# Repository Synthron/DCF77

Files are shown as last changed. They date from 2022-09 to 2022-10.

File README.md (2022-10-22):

# DCF77

DCF77-Clock with Multi-LED display with STM32

---

## Decription

This DCF77 Clock not only displays the time and date, but also analyzes and visualizes the signal received.  
The LED rings are placed as such that each LED is on its respective position on a standard clock face.  
The 7 Segment Displays show the time and date in a more readable format.

### Inner LED Ring

The inner LED ring clocks in the data for the current minute telegram. Each "1"-bit will be displayed by the LED lit up, on a "0", the LED is off respectively.

### Outer LED Ring

The outer LED ring gets updated after the current minute data is complete. On the "0-Second"-Mark, the data from the inner ring gets pushed to the outer ring and analyzed. The resulting data will then be displayed on the 7-Segment-Displays as well as the status LEDs. Also at each full hour, the internal RTC gets updated.

### RTC behaviour

1. Initial startup  
After the initial power-up the current RTC value will be pushed to the displays. This time information can only be trusted, once the module has received a valid telegram and was not powered down for more than 3 days.  
2. First received data  
Once the first valid data was received, it will be pushed into the RTC to update it. After successful write, the RTC_LOCK-LED will be on to indicate trustful data stored in the RTC.  
3. On the hour  
To mitigate possible clock drift, the RTC will be updated on the full hour. This ensures up-to-date data stored in it.

---

## Roadmap Hardware

- [x] finalize schematic
- [x] Set footprints
- [x] decide LED layout
  - all on one board
  - ~~seperate frontpanel pcb~~
- [x] Draw Layout
- [x] Review by theBrutzler
- [x] Order Parts
- [x] check footprints
- [x] Order PCB
- [x] Assemble

---

## Roadmap Software

- [ ] get USB running (for Debug)
- [x] Get DCF77 Antenna working and bits decoded
- [x] get MCP7221 running
- [x] get shift registers running
- [x] set up flags for stats and data
- [x] get LED rings running
- [x] get RTC running
- [x] Sync everything to start of minute/second
- [ ] get everything running together

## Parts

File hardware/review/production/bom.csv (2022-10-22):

Designator | Footprint | Quantity | Value | LCSC Part #
AFF401, AFF402, AFF403, AFF404, AFF405, AFF406, AFF407, AFF408, AFF409, AFF410, AFF411, AFF412, AFF413, AFF414, AFF415, AFF416, AFF417, AFF418, AFF419, AFF420 | 7_Segment_SMD | 20 | LTS-6980HR
C1 | C_0805_2012Metric | 1 | 4µ7
C201, C301, C401, C402, C403, C404, C502, C505, C506, C508, C514, C515, C518, C521, C522, C523, C524, C525, C526 | C_0805_2012Metric | 19 | 100n
C501 | CP_Elec_10x10.5 | 1 | 0.22F/5V5
C503 | CP_Elec_5x5.8 | 1 | 100µ
C504, C507, C513, C516 | C_0805_2012Metric | 4 | 1µ
C509, C510, C511, C512 | C_0805_2012Metric | 4 | 20p
C517 | CP_Elec_5x5.8 | 1 | 10µ
C519, C520 | C_0805_2012Metric | 2 | 47p
D201, D202, D203, D204, D205, D206, D207, D208, D209, D210, D211, D212, D213, D214, D215, D216, D217, D218, D219, D220, D221, D222, D223, D224, D225, D226, D227, D228, D229, D230, D231, D232, D233, D234, D235, D236, D237, D238, D239, D240, D241, D242, D243, D244, D245, D246, D247, D248, D249, D250, D251, D252, D253, D254, D255, D256, D257, D258, D259, D301, D302, D303, D304, D305, D306, D307, D308, D309, D310, D311, D312, D313, D314, D315, D316, D317, D318, D319, D320, D321, D322, D323, D324, D325, D326, D327, D328, D329, D330, D331, D332, D333, D334, D335, D336, D337, D338, D339, D340, D341, D342, D343, D344, D345, D346, D347, D348, D349, D350, D351, D352, D353, D354, D355, D356, D357, D358, D359 | LED_0603_1608Metric | 118 | LED
D401 | LED_0603_1608Metric | 1 | Mo
D402 | LED_0603_1608Metric | 1 | Di
D403 | LED_0603_1608Metric | 1 | Mi
D404 | LED_0603_1608Metric | 1 | Do
D405 | LED_0603_1608Metric | 1 | Fr
D406 | LED_0603_1608Metric | 1 | Sa
D407 | LED_0603_1608Metric | 1 | So
D408 | LED_0603_1608Metric | 1 | CET
D409 | LED_0603_1608Metric | 1 | CEST
D410 | LED_0603_1608Metric | 1 | P1
D411 | LED_0603_1608Metric | 1 | P2
D412 | LED_0603_1608Metric | 1 | P3
D413 | LED_0603_1608Metric | 1 | PE
D501 | D_MiniMELF | 1 | LL4148
D502 | D_MELF | 1 | SM4007
D503 | LED_0603_1608Metric | 1 | RTC
D504 | LED_0603_1608Metric | 1 | SIG
D505, D506 | SOT-23 | 2 | BAV199
FB501, FB502 | SMB-001 | 2 | FerriteBead
J501 | BarrelJack_Horizontal | 1 | Jack-DC
J502 | PinHeader_1x04_P2.54mm_Vertical | 1 | DCF77 Antenna
J503 | PinHeader_1x04_P2.54mm_Horizontal | 1 | SWD
J504 | USB_B_OST_USB-B1HSxx_Horizontal | 1 | USB_B
Q401, Q402, Q403, Q404, Q405, Q406, Q407, Q408, Q409, Q410, Q411, Q412, Q413, Q501, Q502, Q503, Q504, Q505, Q506, Q507, Q509, Q510, Q511 | SOT-23 | 23 | BSS138
Q508 | SOT-23 | 1 | BC856
R201, R301, R427, R428, R442 | R_0805_2012Metric | 5 | 20k
R401, R402, R403, R404, R405, R406, R407, R408, R409, R410, R411, R412, R413 | R_0805_2012Metric | 13 | R
R414, R416, R418, R420, R422, R424, R426, R430, R432, R434, R436, R438, R440, R501, R502, R503, R506, R508, R511, R512, R513, R514, R516, R518, R519, R520, R521, R523, R528, R529, R535, R536 | R_0805_2012Metric | 32 | 10k
R415, R417, R419, R421, R423, R425, R429, R431, R433, R435, R437, R439, R441, R504, R509, R515, R517, R522, R525, R527, R532, R533, R537 | R_0805_2012Metric | 23 | 100k
R505 | R_0805_2012Metric | 1 | 100
R507, R524, R526 | R_0805_2012Metric | 3 | 1k
R510 | R_0805_2012Metric | 1 | 1M
R530 | R_0805_2012Metric | 1 | 1k5
R531, R534 | R_0805_2012Metric | 2 | 22
U201, U301, U402, U403, U405 | SOIC-24W_7.5x15.4mm_P1.27mm | 5 | MAX7221xWG
U401, U404 | SO-16_3.9x9.9mm_P1.27mm | 2 | 74HC595
U501 | TO-263-2 | 1 | L7805
U502 | SOT-223-3_TabPin2 | 1 | AZ1117-3.3
U503 | LQFP-48_7x7mm_P0.5mm | 1 | STM32F103C8Tx
Y501 | Crystal_SMD_HC49-SD | 1 | 8MHz
Y502 | Crystal_SMD_SeikoEpson_MC306-4Pin_8.0x3.2mm | 1 | 32.768kHz

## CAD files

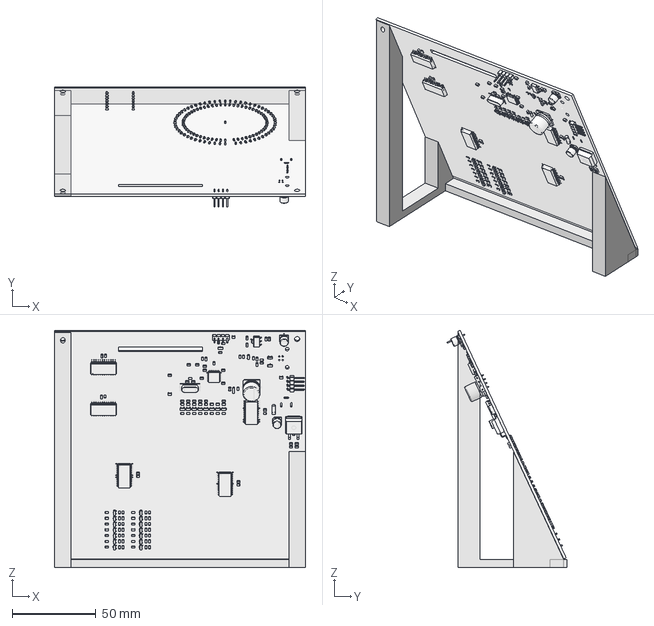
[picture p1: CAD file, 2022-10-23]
hardware/DCF77-Stand_Prototype.FCStd
150.0 x 71.6 x 141.8 mm
PCB

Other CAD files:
hardware/DCF77-Stand_Prototype.stl

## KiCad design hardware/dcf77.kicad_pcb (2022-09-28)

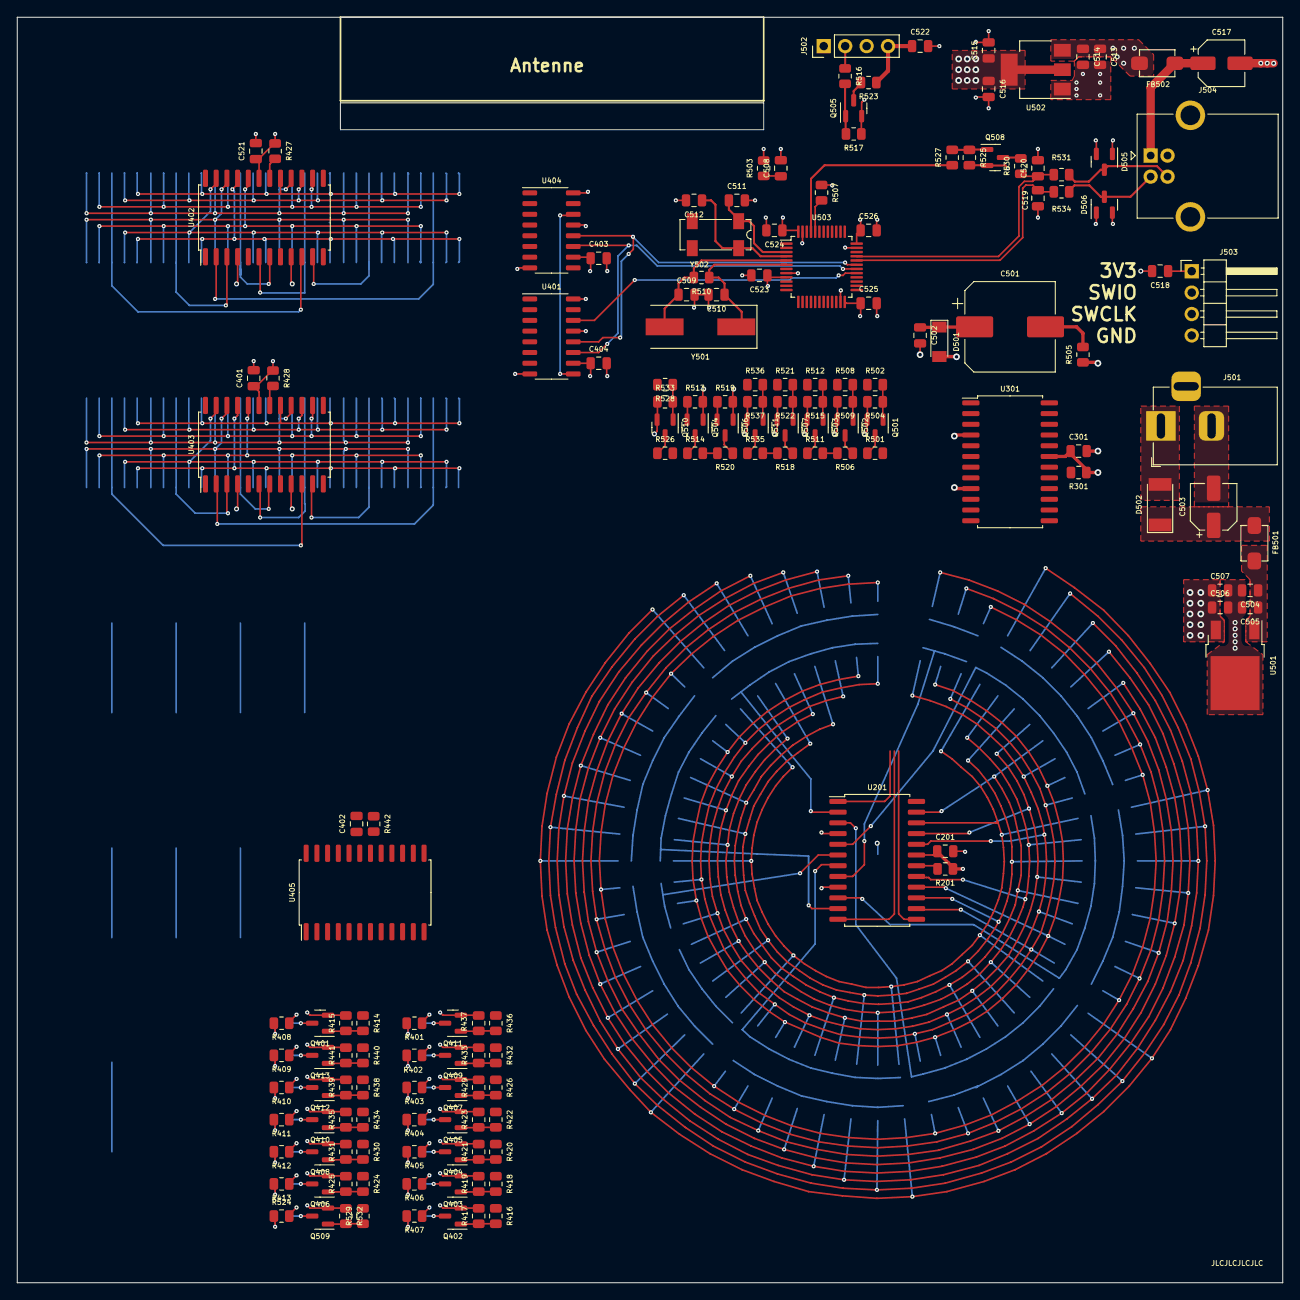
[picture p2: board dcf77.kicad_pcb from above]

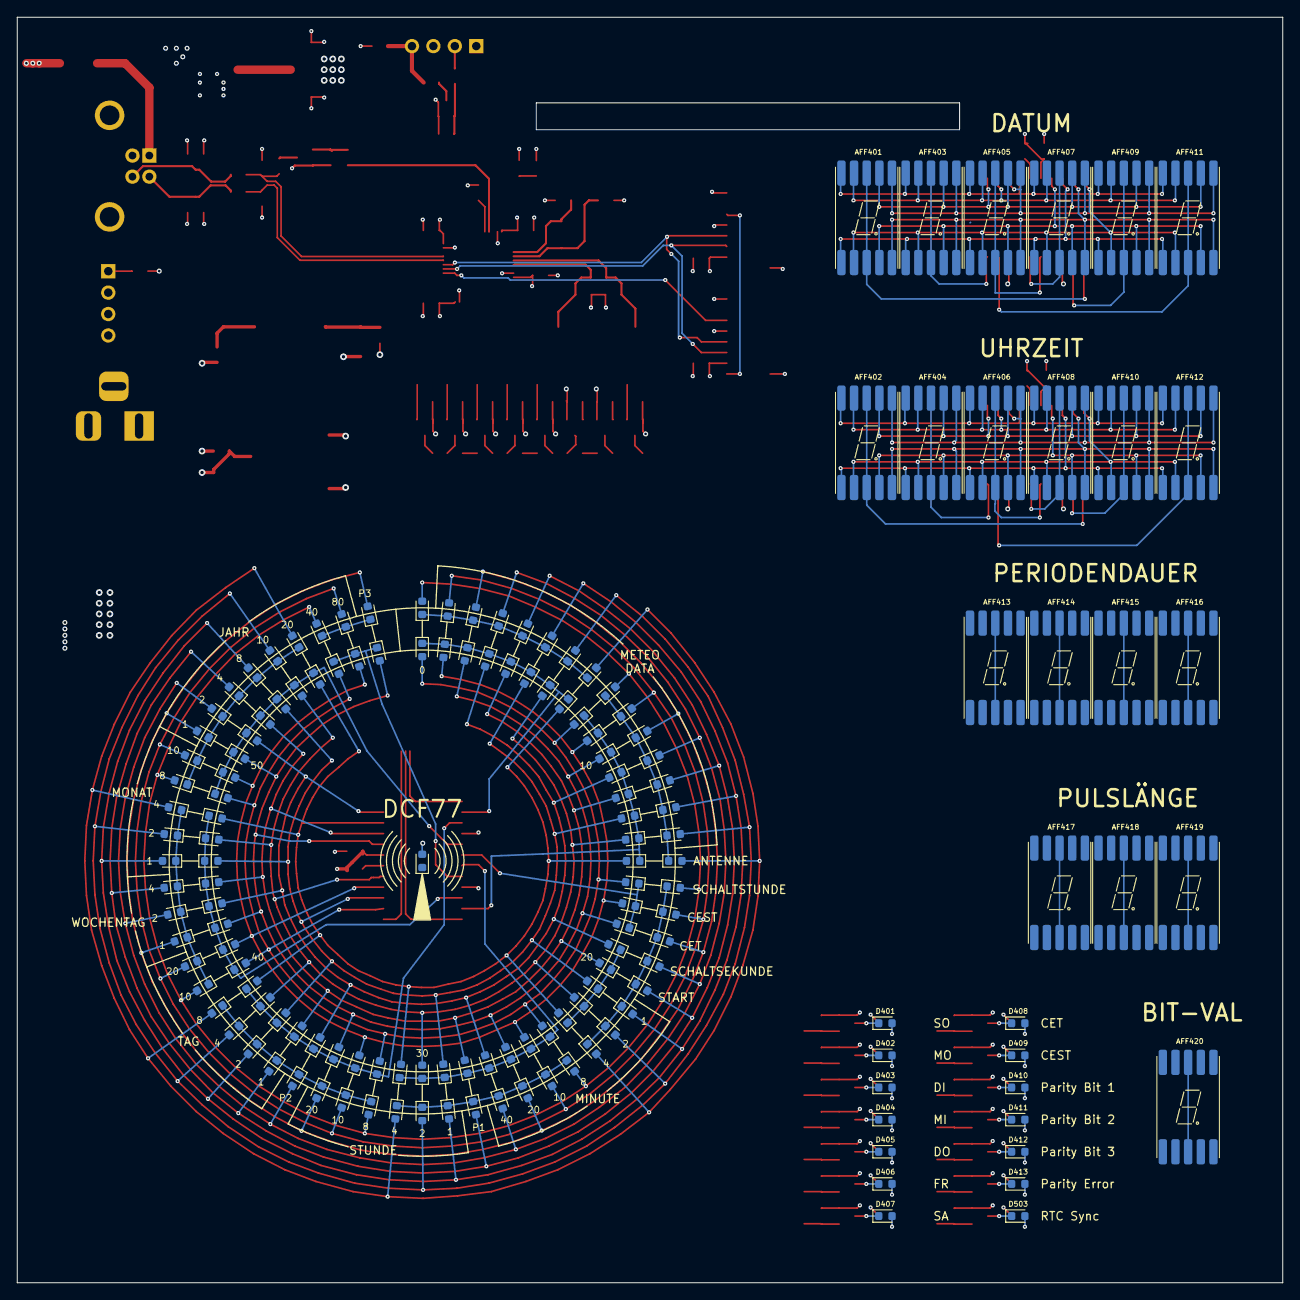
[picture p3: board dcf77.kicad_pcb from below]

Board: 4 copper layers, 150.0 x 150.0 mm, 312 parts (153 on the bottom side), 191 nets.

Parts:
AFF401, AFF402, AFF403, AFF404, AFF405, AFF406, AFF407, AFF408, AFF409, AFF410, AFF411, AFF412, AFF413, AFF414, AFF415, AFF416, AFF417, AFF418, AFF419, AFF420: LTS-6980HR; 7_Segment_SMD
C201, C301, C401, C402, C403, C404, C502, C505, C506, C508, C514, C515, C518, C521, C522, C523, C524, C525, C526: 100n; C_0805_2012Metric
C501: 0.22F/5V5; CP_Elec_10x10.5
C503: 100µ; CP_Elec_5x5.8
C504, C507, C513, C516: 1µ; C_0805_2012Metric
C509, C510, C511, C512: 20p; C_0805_2012Metric
C517: 10µ; CP_Elec_5x5.8
C519, C520: 47p; C_0805_2012Metric
D201, D202, D203, D204, D205, D206, D207, D208, D209, D210, D211, D212, D213, D214, D215, D216, D217, D218, D219, D220, D221, D222, D223, D224, D225, D226, D227, D228, D229, D230, D231, D232, D233, D234, D235, D236, D237, D238, D239, D240, D241, D242, D243, D244, D245, D246, D247, D248, D249, D250, D251, D252, D253, D254, D255, D256, D257, D258, D259, D301, D302, D303, D304, D305, D306, D307, D308, D309, D310, D311, D312, D313, D314, D315, D316, D317, D318, D319, D320, D321, D322, D323, D324, D325, D326, D327, D328, D329, D330, D331, D332, D333, D334, D335, D336, D337, D338, D339, D340, D341, D342, D343, D344, D345, D346, D347, D348, D349, D350, D351, D352, D353, D354, D355, D356, D357, D358, D359: LED; LED_0603_1608Metric
D401: Mo; LED_0603_1608Metric
D402: Di; LED_0603_1608Metric
D403: Mi; LED_0603_1608Metric
D404: Do; LED_0603_1608Metric
D405: Fr; LED_0603_1608Metric
D406: Sa; LED_0603_1608Metric
D407: So; LED_0603_1608Metric
D408: CET; LED_0603_1608Metric
D409: CEST; LED_0603_1608Metric
D410: P1; LED_0603_1608Metric
D411: P2; LED_0603_1608Metric
D412: P3; LED_0603_1608Metric
D413: PE; LED_0603_1608Metric
D501: LL4148; D_MiniMELF
D502: SM4007; D_MELF
D503: RTC; LED_0603_1608Metric
D504: SIG; LED_0603_1608Metric
D505, D506: BAV199; SOT-23
FB501, FB502: FerriteBead; SMB-001
J501: Jack-DC; BarrelJack_Horizontal
J502: DCF77 Antenna; PinHeader_1x04_P2.54mm_Vertical
J503: SWD; PinHeader_1x04_P2.54mm_Horizontal
J504: USB_B; USB_B_OST_USB-B1HSxx_Horizontal
Q401, Q402, Q403, Q404, Q405, Q406, Q407, Q408, Q409, Q410, Q411, Q412, Q413, Q501, Q502, Q503, Q504, Q505, Q506, Q507, Q509, Q510, Q511: BSS138; SOT-23
Q508: BC856; SOT-23
R201, R301, R427, R428, R442: 20k; R_0805_2012Metric
R401, R402, R403, R404, R405, R406, R407, R408, R409, R410, R411, R412, R413: R; R_0805_2012Metric
R414, R416, R418, R420, R422, R424, R426, R430, R432, R434, R436, R438, R440, R501, R502, R503, R505, R506, R507, R508, R511, R512, R513, R514, R516, R518, R519, R520, R521, R523, R528, R529, R535, R536: 10k; R_0805_2012Metric
R415, R417, R419, R421, R423, R425, R429, R431, R433, R435, R437, R439, R441, R504, R509, R515, R517, R522, R525, R527, R532, R533, R537: 100k; R_0805_2012Metric
R510: 1M; R_0805_2012Metric
R524, R526: 1k; R_0805_2012Metric
R530: 1k5; R_0805_2012Metric
R531, R534: 22; R_0805_2012Metric
U201, U301, U402, U403, U405: MAX7221xWG; SOIC-24W_7.5x15.4mm_P1.27mm
U401, U404: 74HC595; SO-16_3.9x9.9mm_P1.27mm
U501: L7805; TO-252-2
U502: AZ1117-3.3; SOT-223-3_TabPin2
U503: STM32F103C8Tx; LQFP-48_7x7mm_P0.5mm
Y501: 8MHz; Crystal_SMD_HC49-SD
Y502: 32.768kHz; Crystal_SMD_SeikoEpson_MC306-4Pin_8.0x3.2mm

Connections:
+3V3: C403.1, C404.1, C515.1, C516.1, C518.1, C522.1, C523.1, C524.1, C525.1, C526.1, D501.2 (A), D505.2, D506.2, J502.4, J503.1, Q504.1 (G), Q506.1 (G), Q508.2 (E), R503.2, R513.2, R519.2, R523.1, R525.2, U401.10 (~SRCLR), U401.16 (VCC), U404.10 (~SRCLR), U404.16 (VCC), U502.2 (VO), U503.9 (VDDA), U503.24 (VDD), U503.36 (VDD), U503.48 (VDD)
+5V: C201.1, C301.1, C401.1, C402.1, C506.1, C507.1, C513.1, C514.1, C521.1, D504.2 (A), FB502.2, R201.1, R301.1, R401.1, R402.1, R403.1, R404.1, R405.1, R406.1, R407.1, R408.1, R409.1, R410.1, R411.1, R412.1, R413.1, R427.1, R428.1, R442.1, R501.2, R506.2, R511.2, R514.2, R518.2, R520.2, R524.2, R535.2, U201.19 (V+), U301.19 (V+), U402.19 (V+), U403.19 (V+), U405.19 (V+), U501.3 (OUT), U502.3 (VI)
/CPU/CLK: Q504.3 (D), R514.1, U201.13 (CLK), U301.13 (CLK), U402.13 (CLK), U403.13 (CLK), U405.13 (CLK)
/CPU/MOSI: Q506.3 (D), R520.1, U201.1 (DIN), U301.1 (DIN), U402.1 (DIN), U403.1 (DIN), U405.1 (DIN)
/CPU/SER_CLK: U401.11 (SRCLK), U404.11 (SRCLK), U503.30 (PA9)
/CPU/SER_Data: U401.14 (SER), U503.29 (PA8)
/CPU/SER_Latch: U401.12 (RCLK), U404.12 (RCLK), U503.31 (PA10)
GND: C201.2, C301.2, C401.2, C402.2, C403.2, C404.2, C502.2, C503.2, C504.2, C505.2, C506.2, C507.2, C508.2, C509.2, C510.2, C511.2, C512.2, C513.2, C514.2, C515.2, C516.2, C517.2, C518.2, C519.2, C520.2, C521.2, C522.2, C523.2, C524.2, C525.2, C526.2, D505.1, D506.1, J501.2, J502.3, J503.4, J504.4 (GND), J504.5 (Shield), Q401.2 (S), Q402.2 (S), Q403.2 (S), Q404.2 (S), Q405.2 (S), Q406.2 (S), Q407.2 (S), Q408.2 (S), Q409.2 (S), Q410.2 (S), Q411.2 (S), Q412.2 (S), Q413.2 (S), Q501.2 (S), Q502.2 (S), Q503.2 (S), Q505.2 (S), Q507.2 (S), Q509.2 (S), Q510.2 (S), Q511.2 (S), R415.2, R417.2, R419.2, R421.2, R423.2, R425.2, R429.2, R431.2, R433.2, R435.2, R437.2, R439.2, R441.2, R504.2, R505.1, R507.1, R509.2, R515.2, R517.1, R522.2, R532.1, R533.1, R537.2, U201.4 (GND), U201.9 (GND), U301.4 (GND), U301.9 (GND), U401.8 (GND), U401.13 (~OE), U402.4 (GND), U402.9 (GND), U403.4 (GND), U403.9 (GND), U404.8 (GND), U404.13 (~OE), U405.4 (GND), U405.9 (GND), U501.2 (GND), U502.1 (GND), U503.8 (VSSA), U503.23 (VSS), U503.35 (VSS), U503.47 (VSS)
unnamed: AFF401.1 (e), AFF403.1 (e), AFF405.1 (e), AFF407.1 (e), AFF409.1 (e), AFF411.1 (e), U402.21 (SEG_E)
unnamed: AFF401.2 (d), AFF403.2 (d), AFF405.2 (d), AFF407.2 (d), AFF409.2 (d), AFF411.2 (d), U402.23 (SEG_D)
unnamed: AFF401.3 (C.K.), AFF401.8 (C.K.), U402.2 (DIG_0)
unnamed: AFF401.4 (c), AFF403.4 (c), AFF405.4 (c), AFF407.4 (c), AFF409.4 (c), AFF411.4 (c), U402.20 (SEG_C)
unnamed: AFF401.5 (DP), AFF403.5 (DP), AFF405.5 (DP), AFF407.5 (DP), AFF409.5 (DP), AFF411.5 (DP), U402.22 (SEG_DP)
unnamed: AFF401.6 (b), AFF403.6 (b), AFF405.6 (b), AFF407.6 (b), AFF409.6 (b), AFF411.6 (b), U402.16 (SEG_B)
unnamed: AFF401.7 (a), AFF403.7 (a), AFF405.7 (a), AFF407.7 (a), AFF409.7 (a), AFF411.7 (a), U402.14 (SEG_A)
unnamed: AFF401.9 (f), AFF403.9 (f), AFF405.9 (f), AFF407.9 (f), AFF409.9 (f), AFF411.9 (f), U402.15 (SEG_F)
unnamed: AFF401.10 (g), AFF403.10 (g), AFF405.10 (g), AFF407.10 (g), AFF409.10 (g), AFF411.10 (g), U402.17 (SEG_G)
unnamed: AFF402.1 (e), AFF404.1 (e), AFF406.1 (e), AFF408.1 (e), AFF410.1 (e), AFF412.1 (e), U403.21 (SEG_E)
unnamed: AFF402.2 (d), AFF404.2 (d), AFF406.2 (d), AFF408.2 (d), AFF410.2 (d), AFF412.2 (d), U403.23 (SEG_D)
unnamed: AFF402.3 (C.K.), AFF402.8 (C.K.), U403.2 (DIG_0)
unnamed: AFF402.4 (c), AFF404.4 (c), AFF406.4 (c), AFF408.4 (c), AFF410.4 (c), AFF412.4 (c), U403.20 (SEG_C)
unnamed: AFF402.5 (DP), AFF404.5 (DP), AFF406.5 (DP), AFF408.5 (DP), AFF410.5 (DP), AFF412.5 (DP), U403.22 (SEG_DP)
unnamed: AFF402.6 (b), AFF404.6 (b), AFF406.6 (b), AFF408.6 (b), AFF410.6 (b), AFF412.6 (b), U403.16 (SEG_B)
unnamed: AFF402.7 (a), AFF404.7 (a), AFF406.7 (a), AFF408.7 (a), AFF410.7 (a), AFF412.7 (a), U403.14 (SEG_A)
unnamed: AFF402.9 (f), AFF404.9 (f), AFF406.9 (f), AFF408.9 (f), AFF410.9 (f), AFF412.9 (f), U403.15 (SEG_F)
unnamed: AFF402.10 (g), AFF404.10 (g), AFF406.10 (g), AFF408.10 (g), AFF410.10 (g), AFF412.10 (g), U403.17 (SEG_G)
unnamed: AFF403.3 (C.K.), AFF403.8 (C.K.), U402.11 (DIG_1)
unnamed: AFF404.3 (C.K.), AFF404.8 (C.K.), U403.11 (DIG_1)
unnamed: AFF405.3 (C.K.), AFF405.8 (C.K.), U402.6 (DIG_2)
unnamed: AFF406.3 (C.K.), AFF406.8 (C.K.), U403.6 (DIG_2)
unnamed: AFF407.3 (C.K.), AFF407.8 (C.K.), U402.7 (DIG_3)
unnamed: AFF408.3 (C.K.), AFF408.8 (C.K.), U403.7 (DIG_3)
unnamed: AFF409.3 (C.K.), AFF409.8 (C.K.), U402.3 (DIG_4)
unnamed: AFF410.3 (C.K.), AFF410.8 (C.K.), U403.3 (DIG_4)
unnamed: AFF411.3 (C.K.), AFF411.8 (C.K.), U402.10 (DIG_5)
unnamed: AFF412.3 (C.K.), AFF412.8 (C.K.), U403.10 (DIG_5)
unnamed: AFF413.3 (C.K.), AFF413.8 (C.K.), U405.2 (DIG_0)
unnamed: AFF413.5 (DP), AFF414.5 (DP), AFF415.5 (DP), U405.22 (SEG_DP)
unnamed: AFF414.3 (C.K.), AFF414.8 (C.K.), U405.11 (DIG_1)
unnamed: AFF415.1 (e), AFF416.1 (e), AFF417.1 (e), AFF418.1 (e), AFF419.1 (e), AFF420.1 (e), U405.21 (SEG_E)
unnamed: AFF415.2 (d), AFF416.2 (d), AFF417.2 (d), AFF418.2 (d), AFF419.2 (d), AFF420.2 (d), U405.23 (SEG_D)
unnamed: AFF415.3 (C.K.), AFF415.8 (C.K.), U405.6 (DIG_2)
unnamed: AFF415.4 (c), AFF416.4 (c), AFF417.4 (c), AFF418.4 (c), AFF419.4 (c), AFF420.4 (c), U405.20 (SEG_C)
unnamed: AFF415.6 (b), AFF416.6 (b), AFF417.6 (b), AFF418.6 (b), AFF419.6 (b), AFF420.6 (b), U405.16 (SEG_B)
unnamed: AFF415.7 (a), AFF416.7 (a), AFF417.7 (a), AFF418.7 (a), AFF419.7 (a), AFF420.7 (a), U405.14 (SEG_A)
unnamed: AFF415.9 (f), AFF416.9 (f), AFF417.9 (f), AFF418.9 (f), AFF419.9 (f), AFF420.9 (f), U405.15 (SEG_F)
unnamed: AFF415.10 (g), AFF416.10 (g), AFF417.10 (g), AFF418.10 (g), AFF419.10 (g), AFF420.10 (g), U405.17 (SEG_G)
unnamed: AFF416.3 (C.K.), AFF416.8 (C.K.), U405.7 (DIG_3)
unnamed: AFF417.3 (C.K.), AFF417.8 (C.K.), U405.3 (DIG_4)
unnamed: AFF418.3 (C.K.), AFF418.8 (C.K.), U405.10 (DIG_5)
unnamed: AFF419.3 (C.K.), AFF419.8 (C.K.), U405.5 (DIG_6)
unnamed: AFF420.3 (C.K.), AFF420.8 (C.K.), U405.8 (DIG_7)
unnamed: C501.1, C502.1, D501.1 (K), U503.1 (VBAT)
unnamed: C501.2, R505.2
unnamed: C503.1, D502.1 (K), FB501.1
unnamed: C508.1, R503.1, U503.7 (NRST)
unnamed: C509.1, R510.2, U503.5 (PD0), Y501.2
unnamed: C510.1, R510.1, U503.6 (PD1), Y501.1
unnamed: C511.1, U503.3 (PC14), Y502.1
unnamed: C512.1, U503.4 (PC15), Y502.4
unnamed: C517.1, FB502.1, J504.1 (VBUS)
unnamed: D201.1 (K), D202.1 (K), D203.1 (K), D204.1 (K), D205.1 (K), D206.1 (K), D207.1 (K), D208.1 (K), U201.2 (DIG_0)
unnamed: D201.2 (A), D209.2 (A), D217.2 (A), D225.2 (A), D233.2 (A), D241.2 (A), D249.2 (A), D257.2 (A), U201.14 (SEG_A)
unnamed: D202.2 (A), D210.2 (A), D218.2 (A), D226.2 (A), D234.2 (A), D242.2 (A), D250.2 (A), D258.2 (A), U201.16 (SEG_B)
unnamed: D203.2 (A), D211.2 (A), D219.2 (A), D227.2 (A), D235.2 (A), D243.2 (A), D251.2 (A), D259.2 (A), U201.20 (SEG_C)
unnamed: D204.2 (A), D212.2 (A), D220.2 (A), D228.2 (A), D236.2 (A), D244.2 (A), D252.2 (A), U201.23 (SEG_D)
unnamed: D205.2 (A), D213.2 (A), D221.2 (A), D229.2 (A), D237.2 (A), D245.2 (A), D253.2 (A), U201.21 (SEG_E)
unnamed: D206.2 (A), D214.2 (A), D222.2 (A), D230.2 (A), D238.2 (A), D246.2 (A), D254.2 (A), U201.15 (SEG_F)
unnamed: D207.2 (A), D215.2 (A), D223.2 (A), D231.2 (A), D239.2 (A), D247.2 (A), D255.2 (A), U201.17 (SEG_G)
unnamed: D208.2 (A), D216.2 (A), D224.2 (A), D232.2 (A), D240.2 (A), D248.2 (A), D256.2 (A), U201.22 (SEG_DP)
unnamed: D209.1 (K), D210.1 (K), D211.1 (K), D212.1 (K), D213.1 (K), D214.1 (K), D215.1 (K), D216.1 (K), U201.11 (DIG_1)
unnamed: D217.1 (K), D218.1 (K), D219.1 (K), D220.1 (K), D221.1 (K), D222.1 (K), D223.1 (K), D224.1 (K), U201.6 (DIG_2)
unnamed: D225.1 (K), D226.1 (K), D227.1 (K), D228.1 (K), D229.1 (K), D230.1 (K), D231.1 (K), D232.1 (K), U201.7 (DIG_3)
unnamed: D233.1 (K), D234.1 (K), D235.1 (K), D236.1 (K), D237.1 (K), D238.1 (K), D239.1 (K), D240.1 (K), U201.3 (DIG_4)
unnamed: D241.1 (K), D242.1 (K), D243.1 (K), D244.1 (K), D245.1 (K), D246.1 (K), D247.1 (K), D248.1 (K), U201.10 (DIG_5)
unnamed: D249.1 (K), D250.1 (K), D251.1 (K), D252.1 (K), D253.1 (K), D254.1 (K), D255.1 (K), D256.1 (K), U201.5 (DIG_6)
unnamed: D257.1 (K), D258.1 (K), D259.1 (K), U201.8 (DIG_7)
unnamed: D301.1 (K), D302.1 (K), D303.1 (K), D304.1 (K), D305.1 (K), D306.1 (K), D307.1 (K), D308.1 (K), U301.2 (DIG_0)
unnamed: D301.2 (A), D309.2 (A), D317.2 (A), D325.2 (A), D333.2 (A), D341.2 (A), D349.2 (A), D357.2 (A), U301.14 (SEG_A)
unnamed: D302.2 (A), D310.2 (A), D318.2 (A), D326.2 (A), D334.2 (A), D342.2 (A), D350.2 (A), D358.2 (A), U301.16 (SEG_B)
unnamed: D303.2 (A), D311.2 (A), D319.2 (A), D327.2 (A), D335.2 (A), D343.2 (A), D351.2 (A), D359.2 (A), U301.20 (SEG_C)
unnamed: D304.2 (A), D312.2 (A), D320.2 (A), D328.2 (A), D336.2 (A), D344.2 (A), D352.2 (A), U301.23 (SEG_D)
unnamed: D305.2 (A), D313.2 (A), D321.2 (A), D329.2 (A), D337.2 (A), D345.2 (A), D353.2 (A), U301.21 (SEG_E)
unnamed: D306.2 (A), D314.2 (A), D322.2 (A), D330.2 (A), D338.2 (A), D346.2 (A), D354.2 (A), U301.15 (SEG_F)
unnamed: D307.2 (A), D315.2 (A), D323.2 (A), D331.2 (A), D339.2 (A), D347.2 (A), D355.2 (A), U301.17 (SEG_G)
unnamed: D308.2 (A), D316.2 (A), D324.2 (A), D332.2 (A), D340.2 (A), D348.2 (A), D356.2 (A), U301.22 (SEG_DP)
unnamed: D309.1 (K), D310.1 (K), D311.1 (K), D312.1 (K), D313.1 (K), D314.1 (K), D315.1 (K), D316.1 (K), U301.11 (DIG_1)
unnamed: D317.1 (K), D318.1 (K), D319.1 (K), D320.1 (K), D321.1 (K), D322.1 (K), D323.1 (K), D324.1 (K), U301.6 (DIG_2)
unnamed: D325.1 (K), D326.1 (K), D327.1 (K), D328.1 (K), D329.1 (K), D330.1 (K), D331.1 (K), D332.1 (K), U301.7 (DIG_3)
unnamed: D333.1 (K), D334.1 (K), D335.1 (K), D336.1 (K), D337.1 (K), D338.1 (K), D339.1 (K), D340.1 (K), U301.3 (DIG_4)
unnamed: D341.1 (K), D342.1 (K), D343.1 (K), D344.1 (K), D345.1 (K), D346.1 (K), D347.1 (K), D348.1 (K), U301.10 (DIG_5)
unnamed: D349.1 (K), D350.1 (K), D351.1 (K), D352.1 (K), D353.1 (K), D354.1 (K), D355.1 (K), D356.1 (K), U301.5 (DIG_6)
unnamed: D357.1 (K), D358.1 (K), D359.1 (K), U301.8 (DIG_7)
unnamed: D401.1 (K), Q411.3 (D)
unnamed: D401.2 (A), R401.2
unnamed: D402.1 (K), Q409.3 (D)
unnamed: D402.2 (A), R402.2
unnamed: D403.1 (K), Q407.3 (D)
unnamed: D403.2 (A), R403.2
unnamed: D404.1 (K), Q405.3 (D)
unnamed: D404.2 (A), R404.2
unnamed: D405.1 (K), Q404.3 (D)
unnamed: D405.2 (A), R405.2
unnamed: D406.1 (K), Q403.3 (D)
unnamed: D406.2 (A), R406.2
unnamed: D407.1 (K), Q402.3 (D)
unnamed: D407.2 (A), R407.2
unnamed: D408.1 (K), Q401.3 (D)
unnamed: D408.2 (A), R408.2
unnamed: D409.1 (K), Q413.3 (D)
unnamed: D409.2 (A), R409.2
unnamed: D410.1 (K), Q412.3 (D)
unnamed: D410.2 (A), R410.2
unnamed: D411.1 (K), Q410.3 (D)
unnamed: D411.2 (A), R411.2
unnamed: D412.1 (K), Q408.3 (D)
unnamed: D412.2 (A), R412.2
unnamed: D413.1 (K), Q406.3 (D)
unnamed: D413.2 (A), R413.2
unnamed: D502.2 (A), J501.1
unnamed: D503.1 (K), Q509.3 (D)
unnamed: D503.2 (A), R524.1
unnamed: D505.3, J504.3 (D+), R531.1
unnamed: D506.3, J504.2 (D-), R534.1
unnamed: J502.1, U503.27 (PB14)
unnamed: J502.2, R516.1
unnamed: Q401.1 (G), R414.2, R415.1
unnamed: Q402.1 (G), R416.2, R417.1
unnamed: Q403.1 (G), R418.2, R419.1
unnamed: Q404.1 (G), R420.2, R421.1
unnamed: Q405.1 (G), R422.2, R423.1
unnamed: Q406.1 (G), R424.2, R425.1
unnamed: Q407.1 (G), R426.2, R429.1
unnamed: Q408.1 (G), R430.2, R431.1
unnamed: Q409.1 (G), R432.2, R433.1
unnamed: Q410.1 (G), R434.2, R435.1
unnamed: Q411.1 (G), R436.2, R437.1
unnamed: Q412.1 (G), R438.2, R439.1
unnamed: Q413.1 (G), R440.2, R441.1
unnamed: Q501.1 (G), R502.2, R504.1
unnamed: Q501.3 (D), R501.1
unnamed: Q502.1 (G), R508.2, R509.1
unnamed: Q502.3 (D), R506.1
unnamed: Q503.1 (G), R512.2, R515.1
unnamed: Q503.3 (D), R511.1
unnamed: Q504.2 (S), R513.1, U503.15 (PA5)
unnamed: Q505.1 (G), R516.2, R517.2
unnamed: Q505.3 (D), R523.2, R528.2, U503.28 (PB15)
unnamed: Q506.2 (S), R519.1, U503.17 (PA7)
unnamed: Q507.1 (G), R521.2, R522.1
unnamed: Q507.3 (D), R518.1
unnamed: Q508.1 (B), R525.1, R527.2
unnamed: Q508.3 (C), R530.2
unnamed: Q509.1 (G), R529.1, R532.2
unnamed: Q510.1 (G), R528.1, R533.2
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

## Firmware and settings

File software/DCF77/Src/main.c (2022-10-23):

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
/* Includes ------------------------------------------------------------------*/
#include "main.h"
#include "rtc.h"
#include "spi.h"
#include "tim.h"
#include "usb_device.h"
#include "gpio.h"

/* USER CODE BEGIN Includes */

#include "dcf77.h"

/* USER CODE END Includes */

/* USER CODE BEGIN PD */

// Pin Defines
#define CS_Inner GPIO_PIN_0
#define CS_Outer GPIO_PIN_1
#define CS_Date GPIO_PIN_3
#define CS_Time GPIO_PIN_2
#define CS_Pulse GPIO_PIN_4
#define Ser_Data GPIO_PIN_8
#define Ser_Clock GPIO_PIN_9
#define Ser_Latch GPIO_PIN_10
#define RTC_Lock GPIO_PIN_15
#define PON GPIO_PIN_14
#define USB_Connect GPIO_PIN_8

// MAX7221 Defines
#define Dig0 0x1
#define Dig1 0x2
#define Dig2 0x3
#define Dig3 0x4
#define Dig4 0x5
#define Dig5 0x6
#define Dig6 0x7
#define Dig7 0x8
#define DecodeMode 0x9
#define Intensity 0xA
#define ScanLimit 0xB
#define Shutdown 0xC
#define DispTest 0xF

/* USER CODE END PD */


/* USER CODE BEGIN PV */

// timestamp variables
uint32_t pulse_time1, pulse_time2, period_time, temp;

// indicator array:
// CEST-P1-P2-P3-PErr-Mo-Di-Mi-Do-Fr-Sa-So-CET
bool leds[13];

// Minute Telegrams
uint8_t bitno;
bool minute[60];

// time data variable
uint8_t hour_tens, hour_ones,
    minute_tens, minute_ones,
    second_tens, second_ones,
    year_tens, year_ones,
    month_tens, month_ones,
    day_tens, day_ones,
    week,
    bitval, digs, bits;
uint16_t period, pulse;

// SPI
uint8_t data_buf[2];

bool pulse_ok = false, period_ok = false, perr = true;
uint32_t minstart = 0;

uint8_t t, h1, h2, z1, z2, e1, e2;
uint8_t out[8];
char usb_buffer[45];

/* USER CODE END PV */

void SystemClock_Config(void);
/**
 * @brief  The application entry point.
 * @retval int
 */
int main(void)
{
  /* MCU Configuration--------------------------------------------------------*/

  /* Reset of all peripherals, Initializes the Flash interface and the Systick. */
  HAL_Init();

  /* Configure the system clock */
  SystemClock_Config();

  /* Initialize all configured peripherals */
  MX_GPIO_Init();
  MX_RTC_Init();
  MX_SPI1_Init();
  MX_USB_DEVICE_Init();
  MX_TIM1_Init();
  /* USER CODE BEGIN 2 */
  timer_init();

  // Module Init and test routines
  IO_Init();

  RTC_Read();
  HAL_GPIO_WritePin(GPIOB, USB_Connect, 0);

  pulse_time1 = HAL_GetTick();
  pulse_time2 = pulse_time1;
  period_time = pulse_time1;
  temp = pulse_time1;

  /* USER CODE END 2 */

  /* Infinite loop */
  /* USER CODE BEGIN WHILE */
  while (1)
  {
    /* USER CODE END WHILE */

    /* USER CODE BEGIN 3 */
    temp = HAL_GetTick();

    if (period_ok)
    {
      sekundentakt();
    }
    if (pulse_ok)
    {
      pulstakt();
    }
  }
  /* USER CODE END 3 */
}

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
/* USER CODE BEGIN 4 */
void RTC_Read(void)
{
  RTC_DateTypeDef gDate;
  RTC_TimeTypeDef gTime;
  /* Get the RTC current Time */
  HAL_RTC_GetTime(&hrtc, &gTime, RTC_FORMAT_BCD);
  /* Get the RTC current Date */
  HAL_RTC_GetDate(&hrtc, &gDate, RTC_FORMAT_BCD);

  gDate.Year = HAL_RTCEx_BKUPRead(&hrtc, RTC_BKP_DR1);    // backup register
  gDate.Month = HAL_RTCEx_BKUPRead(&hrtc, RTC_BKP_DR2);   // backup register
  gDate.Date = HAL_RTCEx_BKUPRead(&hrtc, RTC_BKP_DR3);    // backup register
  gDate.WeekDay = HAL_RTCEx_BKUPRead(&hrtc, RTC_BKP_DR4); // backup register

  hour_tens = gTime.Hours >> 4;
  hour_ones = gTime.Hours & 0x0F;
  minute_tens = gTime.Minutes >> 4;
  minute_ones = gTime.Minutes & 0x0F;
  year_tens = gDate.Year >> 4;
  year_ones = gDate.Year & 0x0F;
  month_tens = gDate.Month >> 4;
  month_ones = gDate.Month & 0x0F;
  day_tens = gDate.Date >> 4;
  day_ones = gDate.Date & 0x0F;

  MAX7221_Send(CS_Time, Dig0, hour_tens);
  MAX7221_Send(CS_Time, Dig1, hour_ones | 0x80);
  MAX7221_Send(CS_Time, Dig2, minute_tens);
  MAX7221_Send(CS_Time, Dig3, minute_ones | 0x80);

  MAX7221_Send(CS_Date, Dig0, day_tens);
  MAX7221_Send(CS_Date, Dig1, day_ones | 0x80);
  MAX7221_Send(CS_Date, Dig2, month_tens);
  MAX7221_Send(CS_Date, Dig3, month_ones | 0x80);
  MAX7221_Send(CS_Date, Dig4, year_tens);
  MAX7221_Send(CS_Date, Dig5, year_ones);
}

void RTC_Write(void)
{
  __HAL_RTC_WRITEPROTECTION_DISABLE(&hrtc);
  HAL_PWR_EnableBkUpAccess();
  RTC_TimeTypeDef sTime;
  RTC_DateTypeDef sDate;
  sTime.Hours = (hour_tens << 4) + hour_ones;       // set hours
  sTime.Minutes = (minute_tens << 4) + minute_ones; // set minutes
  sTime.Seconds = 0x00;                             // set seconds
  sDate.Month = (month_tens << 4) + month_ones;     // month
  sDate.Date = (day_tens << 4) + day_ones;          // date
  sDate.Year = (year_tens << 4) + year_ones;        // year

  HAL_RTC_SetDate(&hrtc, &sDate, RTC_FORMAT_BCD);
  HAL_RTC_SetTime(&hrtc, &sTime, RTC_FORMAT_BCD);
  HAL_RTCEx_BKUPWrite(&hrtc, RTC_BKP_DR1, sDate.Year);  // backup register
  HAL_RTCEx_BKUPWrite(&hrtc, RTC_BKP_DR2, sDate.Month); // backup register
  HAL_RTCEx_BKUPWrite(&hrtc, RTC_BKP_DR3, sDate.Date);  // backup register
  HAL_RTCEx_BKUPWrite(&hrtc, RTC_BKP_DR4, week);        // backup register
  HAL_GPIO_WritePin(GPIOA, RTC_Lock, 1);
}

void sekundentakt(void)
{
  uint32_t temp1 = pulse_time1 - period_time;
  e1 = temp1 % 10;
  z1 = ((temp1 % 100) - e1) / 10;
  h1 = ((temp1 % 1000) - z1) / 100;
  t = (temp1 - h1) / 1000;

  MAX7221_Send(CS_Pulse, Dig0, t | 0x80);
  MAX7221_Send(CS_Pulse, Dig1, h1);
  MAX7221_Send(CS_Pulse, Dig2, z1);
  MAX7221_Send(CS_Pulse, Dig3, e1);

  if (temp1 > 1500)
  {
    minstart++;
    bitno = 0;
    digs = 0;
    bits = 0;

    for (int i = 1; i < 9; i++)
    {
      MAX7221_Send(CS_Outer, i, out[i - 1]);
    }
    for (int i = 1; i < 9; i++)
    {
      MAX7221_Send(CS_Inner, i, 0x0);
    }
    analyze();
    if (minstart < 2)
    {
      RTC_Read();
      if (minstart == 1)
      {
        minute_ones++;
        if (minute_ones == 10)
        {
          minute_ones = 0;
          minute_tens++;
          if (minute_tens == 6)
          {
            minute_tens = 0;
            hour_ones++;
            if (hour_ones == 10)
            {
              hour_ones = 0;
              hour_tens++;
            }
          }
        }
        MAX7221_Send(CS_Time, Dig0, hour_tens);
        MAX7221_Send(CS_Time, Dig1, hour_ones | 0x80);
        MAX7221_Send(CS_Time, Dig2, minute_tens);
        MAX7221_Send(CS_Time, Dig3, minute_ones | 0x80);
      }
    }
    else
    {
      sprintf(usb_buffer, "Es ist der %d%d.%d%d.20%d%d um %d%d:%d%d:00 Uhr.\r\n",
              day_tens, day_ones,
              month_tens, month_ones,
              year_tens, year_ones,
              hour_tens, hour_ones,
              minute_tens, minute_ones);
      CDC_Transmit_FS(usb_buffer, strlen(usb_buffer));
    }
    if (((hour_ones + hour_tens) > 0) && ((hour_ones + (hour_tens << 4)) < 24) && ((minute_ones + minute_tens) == 0))
    {
      RTC_Write();
    }
  }

  if (minstart > 0)
  {
    MAX7221_Send(CS_Time, Dig4, (bitno - (bitno % 10)) / 10);
    MAX7221_Send(CS_Time, Dig5, bitno % 10);
  }
  else
  {
    if (bitno % 2)
    {
      MAX7221_Send(CS_Time, Dig4, 0xF);
      MAX7221_Send(CS_Time, Dig5, 0xF);
    }
    else
    {
      MAX7221_Send(CS_Time, Dig4, 0x0);
      MAX7221_Send(CS_Time, Dig5, 0x0);
    }
  }
  period_ok = false;
}

void pulstakt(void)
{
  uint32_t p = pulse_time2 - pulse_time1;
  e2 = p % 10;
  z2 = (p % 100 - e2) / 10;
  h2 = (p % 1000 - z2) / 100;

  MAX7221_Send(CS_Pulse, Dig4, h2);
  MAX7221_Send(CS_Pulse, Dig5, z2);
  MAX7221_Send(CS_Pulse, Dig6, e2);

  if ((pulse_time2 - pulse_time1) > 120)
  {
    MAX7221_Send(CS_Pulse, Dig7, 1);
    bitval = 1;
  }
  else
  {
    MAX7221_Send(CS_Pulse, Dig7, 0);
    bitval = 0;
  }
  pulse_ok = false;

  if (minstart > 0)
  {
    switch (bitno % 8)
    {
    case 0:
      bits |= bitval << 6;
      break;
    case 1:
      bits |= bitval << 5;
      break;
    case 2:
      bits |= bitval << 4;
      break;
    case 3:
      bits |= bitval << 3;
      break;
    case 4:
      bits |= bitval << 2;
      break;
    case 5:
      bits |= bitval << 1;
      break;
    case 6:
      bits |= bitval << 0;
      break;
    case 7:
      bits |= bitval << 7;
      break;
    }
    digs = (bitno - (bitno % 8)) / 8;
    minute[bitno] = bitval;

    out[digs] = bits;

    MAX7221_Send(CS_Inner, digs + 1, bits);
  }
  bitno++;
  if (!(bitno % 8))
  {
    bits = 0;
  }
}

void analyze(void)
{
  minute_ones = minute[21] +
                minute[22] * 2 +
                minute[23] * 4 +
                minute[24] * 8;
  minute_tens = minute[25] +
                minute[26] * 2 +
                minute[27] * 4;

  hour_ones = minute[29] +
              minute[30] * 2 +
              minute[31] * 4 +
              minute[32] * 8;
  hour_tens = minute[33] +
              minute[34] * 2;

  day_ones = minute[36] +
             minute[37] * 2 +
             minute[38] * 4 +
             minute[39] * 8;
  day_tens = minute[40] +
             minute[41] * 2;

  month_ones = minute[45] +
               minute[46] * 2 +
               minute[47] * 4 +
               minute[48] * 8;
  month_tens = minute[49];

  year_ones = minute[50] +
              minute[51] * 2 +
              minute[52] * 4 +
              minute[53] * 8;
  year_tens = minute[54] +
              minute[55] * 2 +
              minute[56] * 4 +
              minute[57] * 8;

  week = minute[42] +
         minute[43] * 2 +
         minute[44] * 4;

  bool mo = false, di = false, mi = false, d = false, fr = false, sa = false, so = false;
  switch (week)
  {
  case 1:
    mo = true;
    di = false;
    mi = false;
    d = false;
    fr = false;
    sa = false;
    so = false;
    break;
  case 2:
    mo = false;
    di = true;
    mi = false;
    d = false;
    fr = false;
    sa = false;
    so = false;
    break;
  case 3:
    mo = false;
    di = false;
    mi = true;
    d = false;
    fr = false;
    sa = false;
    so = false;
    break;
  case 4:
    mo = false;
    di = false;
    mi = false;
    d = true;
    fr = false;
    sa = false;
    so = false;
    break;
  case 5:
    mo = false;
    di = false;
    mi = false;
    d = false;
    fr = true;
    sa = false;
    so = false;
    break;
  case 6:
    mo = false;
    di = false;
    mi = false;
    d = false;
    fr = false;
    sa = true;
    so = false;
    break;
  case 7:
    mo = false;
    di = false;
    mi = false;
    d = false;
    fr = false;
    sa = false;
    so = true;
    break;
  }

  uint8_t parity = 0;
  for (int i = 21; i < 59; i++)
  {
    parity += minute[i];
  }
  if (parity % 2 == 0)
  {
    perr = false;
  }
  else
  {
    perr = true;
  }

  if (!perr && (minstart > 1))
  {
    MAX7221_Send(CS_Time, Dig0, hour_tens);
    MAX7221_Send(CS_Time, Dig1, hour_ones | 0x80);
    MAX7221_Send(CS_Time, Dig2, minute_tens);
    MAX7221_Send(CS_Time, Dig3, minute_ones | 0x80);

    MAX7221_Send(CS_Date, Dig0, day_tens);
    MAX7221_Send(CS_Date, Dig1, day_ones | 0x80);
    MAX7221_Send(CS_Date, Dig2, month_tens);
    MAX7221_Send(CS_Date, Dig3, month_ones | 0x80);
    MAX7221_Send(CS_Date, Dig4, year_tens);
    MAX7221_Send(CS_Date, Dig5, year_ones);
  }
  else
  {
    RTC_Read();
  }

  leds[12] = minute[17];
  leds[11] = minute[28];
  leds[10] = minute[35];
  leds[9] = minute[58];
  leds[8] = perr;
  leds[7] = so;
  leds[6] = mo;
  leds[5] = di;
  leds[4] = mi;
  leds[3] = d;
  leds[2] = fr;
  leds[1] = sa;
  leds[0] = minute[18];

  LED_Indicators(leds);
}

void IO_Init(void)
{
  HAL_GPIO_WritePin(GPIOB, PON, 1);
  HAL_GPIO_WritePin(GPIOB, PON, 0);
  HAL_GPIO_WritePin(GPIOB, USB_Connect, 1);
  HAL_GPIO_WritePin(GPIOA, CS_Inner, 0);
  HAL_GPIO_WritePin(GPIOA, CS_Inner, 0);
  HAL_GPIO_WritePin(GPIOA, CS_Outer, 0);
  HAL_GPIO_WritePin(GPIOA, CS_Date, 0);
  HAL_GPIO_WritePin(GPIOA, CS_Time, 0);
  HAL_GPIO_WritePin(GPIOA, CS_Pulse, 0);
  HAL_GPIO_WritePin(GPIOA, Ser_Clock, 0);
  HAL_GPIO_WritePin(GPIOA, Ser_Data, 0);
  HAL_GPIO_WritePin(GPIOA, Ser_Latch, 0);

  // Inner Ring Init
  MAX7221_Send(CS_Inner, Shutdown, 0x01);
  MAX7221_Send(CS_Inner, ScanLimit, 0x07);
  MAX7221_Send(CS_Inner, Dig0, 0xff);
  MAX7221_Send(CS_Inner, Dig1, 0xff);
  MAX7221_Send(CS_Inner, Dig2, 0xff);
  MAX7221_Send(CS_Inner, Dig3, 0xff);
  MAX7221_Send(CS_Inner, Dig4, 0xff);
  MAX7221_Send(CS_Inner, Dig5, 0xff);
  MAX7221_Send(CS_Inner, Dig6, 0xff);
  MAX7221_Send(CS_Inner, Dig7, 0xff);

  // Outer Ring Init
  MAX7221_Send(CS_Outer, Shutdown, 0x01);
  MAX7221_Send(CS_Outer, ScanLimit, 0x07);
  MAX7221_Send(CS_Outer, Dig0, 0xff);
  MAX7221_Send(CS_Outer, Dig1, 0xff);
  MAX7221_Send(CS_Outer, Dig2, 0xff);
  MAX7221_Send(CS_Outer, Dig3, 0xff);
  MAX7221_Send(CS_Outer, Dig4, 0xff);
  MAX7221_Send(CS_Outer, Dig5, 0xff);
  MAX7221_Send(CS_Outer, Dig6, 0xff);
  MAX7221_Send(CS_Outer, Dig7, 0xff);

  // Date Init
  MAX7221_Send(CS_Date, Shutdown, 0x01);
  MAX7221_Send(CS_Date, ScanLimit, 0x05);
  MAX7221_Send(CS_Date, DecodeMode, 0xFF);
  MAX7221_Send(CS_Date, Dig0, 0x00);
  MAX7221_Send(CS_Date, Dig1, 0x80);
  MAX7221_Send(CS_Date, Dig2, 0x00);
  MAX7221_Send(CS_Date, Dig3, 0x80);
  MAX7221_Send(CS_Date, Dig4, 0x00);
  MAX7221_Send(CS_Date, Dig5, 0x00);

  // Time Init
  MAX7221_Send(CS_Time, Shutdown, 0x01);
  MAX7221_Send(CS_Time, ScanLimit, 0x05);
  MAX7221_Send(CS_Time, DecodeMode, 0xFF);
  MAX7221_Send(CS_Time, Dig0, 0x0);
  MAX7221_Send(CS_Time, Dig1, 0x80);
  MAX7221_Send(CS_Time, Dig2, 0x0);
  MAX7221_Send(CS_Time, Dig3, 0x80);
  MAX7221_Send(CS_Time, Dig4, 0x0);
  MAX7221_Send(CS_Time, Dig5, 0x0);

  // Pulse Init
  MAX7221_Send(CS_Pulse, Shutdown, 0x01);
  MAX7221_Send(CS_Pulse, ScanLimit, 0x07);
  MAX7221_Send(CS_Pulse, DecodeMode, 0xFF);
  MAX7221_Send(CS_Pulse, Dig0, 0x80);
  MAX7221_Send(CS_Pulse, Dig1, 0x0);
  MAX7221_Send(CS_Pulse, Dig2, 0x0);
  MAX7221_Send(CS_Pulse, Dig3, 0x0);
  MAX7221_Send(CS_Pulse, Dig4, 0x0);
  MAX7221_Send(CS_Pulse, Dig5, 0x0);
  MAX7221_Send(CS_Pulse, Dig6, 0x0);
  MAX7221_Send(CS_Pulse, Dig7, 0x0);

  for (int i = 0; i < 13; i++)
    leds[i] = 0;
  LED_Indicators(leds);
}

void MAX7221_Send(uint16_t _pin, uint8_t _reg, uint8_t _data)
{
  data_buf[0] = _reg;
  data_buf[1] = _data;
  delay_us(1);
  HAL_GPIO_WritePin(GPIOA, _pin, 1);
  HAL_SPI_Transmit(&hspi1, (uint8_t *)&data_buf, 2, 100);
  HAL_GPIO_WritePin(GPIOA, _pin, 0);
  delay_us(1);
}

// Update LED Indicators
void LED_Indicators(bool arr[13])
{
  for (int i = 13; i != 0; i--)
  {
    HAL_GPIO_WritePin(GPIOA, Ser_Data, arr[i - 1]);
    delay_us(1);
    HAL_GPIO_WritePin(GPIOA, Ser_Clock, 1);
    delay_us(1);
    HAL_GPIO_WritePin(GPIOA, Ser_Clock, 0);
  }
  delay_us(1);
  HAL_GPIO_WritePin(GPIOA, Ser_Latch, 1);
  delay_us(1);
  HAL_GPIO_WritePin(GPIOA, Ser_Latch, 0);
}

// Interrupt Handler
void HAL_GPIO_EXTI_Callback(uint16_t GPIO_Pin)
{
  if (GPIO_Pin == GPIO_PIN_15)
  {
    if (HAL_GPIO_ReadPin(GPIOB, GPIO_PIN_15) == 0)
    {
      period_time = pulse_time1;
      pulse_time1 = temp;
      period_ok = true;
    }
    else
    {
      pulse_time2 = temp;
      pulse_ok = true;
    }
  }
}

/* USER CODE END 4 */
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


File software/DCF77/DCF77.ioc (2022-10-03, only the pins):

Mcu.UserName=STM32F103C8Tx
PA0-WKUP.Signal=GPIO_Output
PA1.Signal=GPIO_Output
PA10.Signal=GPIO_Output
PA11.Signal=USB_DM
PA12.Signal=USB_DP
PA13.Signal=SYS_JTMS-SWDIO
PA14.Signal=SYS_JTCK-SWCLK
PA15.Signal=GPIO_Output
PA2.Signal=GPIO_Output
PA3.Signal=GPIO_Output
PA4.Signal=GPIO_Output
PA5.Signal=SPI1_SCK
PA7.Signal=SPI1_MOSI
PA8.Signal=GPIO_Output
PA9.Signal=GPIO_Output
PB14.Signal=GPIO_Output
PB15.Signal=GPXTI15
PB8.Signal=GPIO_Output
PC14-OSC32_IN.Signal=RCC_OSC32_IN
PC15-OSC32_OUT.Signal=RCC_OSC32_OUT
PD0-OSC_IN.Signal=RCC_OSC_IN
PD1-OSC_OUT.Signal=RCC_OSC_OUT

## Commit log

2022-09-26 start layout, finalize schematic
    [LED_ring.kicad_sch, Status.kicad_sch, cpu.kicad_sch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]
2022-09-26 update Layout
    [cpu.kicad_sch, dcf77.kicad_pcb]
2022-09-27 update Schematic
    [cpu.kicad_sch, dcf77.kicad_pcb]
2022-09-29 finalize initial routing
    [Status.kicad_sch, cpu.kicad_sch, dcf77.kicad_sch]
2022-10-03 code update
    [dcf77.csv]
2022-10-07 finalize layout
    [dcf77-B_Cu.gbr, dcf77-B_Mask.gbr, dcf77-B_Paste.gbr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]
2022-10-23 update resistor values in Schematic and BOM Bugfix in Code added test stand
    [DCF77-Stand_Prototype.FCStd, DCF77-Stand_Prototype.stl, Status.kicad_sch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]

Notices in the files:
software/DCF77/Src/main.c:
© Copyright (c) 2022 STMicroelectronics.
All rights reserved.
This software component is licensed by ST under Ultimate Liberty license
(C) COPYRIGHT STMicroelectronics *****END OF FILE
